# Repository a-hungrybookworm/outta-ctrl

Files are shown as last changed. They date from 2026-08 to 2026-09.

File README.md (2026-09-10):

# Outta-Ctrl

A custom 64-key linear mechanical keyboard designed from scratch - including a custom PCB, case, firmware, and even keycaps. 



## Features
* Custom PCB & layout
* 3D designed sandwich-mount case
* Custom RMK firmware
* Hotswappable MX-compatible switches
* Screw-in stabilisers
* Custom keycaps

## Components 
* Custom PCB
* 3D-printed case
* MX-compatible switches
* 1N4148 diodes
* Raspberry Pi Pico 
* Hotswap sockets
* Clear screw-in stabilizers
* Blank white (soon-to-be-doodled-on) keycaps

## Design Process
Initially, I planned the 64-key layout for my keyboard, and decided which components I would use. 

I then designed the PCB in KiCAD. I initially figured out which libraries/ footprints to use, connected them to form the keyboard matrix (row-to-col) and finally arranged the components and routed the traces.

Next, I learnt how to 3D model in Onshape, while simultaneously modelling the case. I used a sandwich mount for its simplicity, and split the case into two mutually screwable sections, as it was too big for the bed size. This will help in easy assembly and disassembly.

Finally, I wrote the RMK firmware, which I will flash to my Pi Pico to control the keyboard.

## Why I built it
I've been fascinated by understanding how most everyday objects work, and when I saw a HackClub programme offering to teach me how to build one of them, a keyboard, I was thrilled. Finally, I had the opportunity to learn how to design keyboard PCBs, model their cases, write their custom firmware, and deeply understand how these devices function.

## Challenges
While designing the keyboard, I found several tasks challenging, such as
* understanding the specifications and limitations of the different components
* accounting for all the specific holes and features of the components while designing the 3D models
* finding footprints/ 3D models for my components
* finding keycaps for my design size

## What I learnt
I started this ambitious project with no experience at all, and only a list of tutorials (credit to [Keeb](keeb.hackclub.com)). Now, I've learnt so much, including (sequentially) - 
* how Github repositories function 
* how to write in Markdown, and how to write a readme
* how to design a PCB in KiCAD
* the matrix layout/schematic required for keyboard PCBs
* how to use Onshape for 3D designing
* the different keyboard mounting styles, and parts of a case
* what keyboard firmware does, and how to write it
* about different keyboard components, and their functions

## Images 

__Schematic__:

Schematic

__Routed PCB__: 

 Routed

**3D Models:**

 __Top(Case)__:
 
Top

 __Plate__:

Plate

 __Base__:

Base

__Assembly__:

(without all keycaps/ stabs)

Assembly

## Bill of Materials

| SI No. | Name | Notes | Quantity | Price Per Unit | Total | Running Total | Price/Unit(USD) | Total (USD) | Running Total (USD) | Link |
| --- | --- | --- | --- | --- | --- | --- | --- | --- | --- | --- |
| 1 | Keygeek x MZ Y1 Keyboard Switch (Pack of 10) | MX-compatible Switches | 7 | 300 | 2100 | 2100 | 3.16 | 22.11 | 22.11 | [Switch](http://stackskb.com/store/keygeek-y1-keyboard-switch/) |
| 2 | PCB (manufactured by Robu) | Manufactured by Robu | 5 | 1062 | 5310 | 7410 | 11.18 | 55.89 | 78 | [PCB_Robu](https://github.com/a-hungrybookworm/outta-ctrl/blob/main/BOM/PCB%20Order.png) |
| 3 | Durock Clear Screw-In Stabilizers V2 | Screw-in stabilisers | 1 | 1650 | 1650 | 9060 | 17.37 | 17.37 | 95.37 | [Stabs](http://stackskb.com/store/durock-clear-screw-in-stabilizers-v2/) |
| 4 | Gateron Hotswap Sockets | Hotswap Sockets | 64 | 10 | 640 | 9700 | 0.11 | 6.74 | 102.11 | [Hotswap Switches](http://stackskb.com/store/gateron-hotswap-sockets/) |
| 5 | 1N4148 Diodes | Pack of 100, TH | 1 | 180 | 180 | 9880 | 1.89 | 1.89 | 104 | [Diodes](https://www.flipkart.com/elph-zener-diode-1n4148-pieces-100-electronic-components-hobby-kit/p/itmff7b2uhf4yng4) |
| 6 | Raspberry Pi Pico | MCU | 1 | 384 | 384 | 10264 | 4.04 | 4.04 | 108.04 | [Pico](https://robu.in/product/raspberry-pi-pico/) |
| 7 | Heat Set Threaded Round Female Insert Nut | M3, pack of 5 | 2 | 15 | 30 | 10294 | 0.16 | 0.32 | 108.36 | [Heat Set Insert](https://makerbazar.in/products/brass-heat-set-threaded-round-female-insert-nut?variant=48339035554032) |
| 8 | Philips Head Nuts & Bolts Set | M3, pack of 10 | 1 | 25 | 25 | 10319 | 0.26 | 0.26 | 108.62 | [Screws](https://makerbazar.in/products/philips-head-nuts-bolts-set-silver-plated-pack-of-10?variant=43604554383600) |
| 9 | Blank White Cherry Profile Keycaps | For later customization | 1 | 1000 | 1000 | 11319 | 10.53 | 10.53 | 119.15 | [Keycaps](https://stackskb.com/store/stackspbt-blank-white-cherry-profile-keycaps-113-key/) |
| 10 | 7u Spacebar | Custom key | 1 | 300 | 300 | 11619 | 3.16 | 3.16 | 122.31 | [Spacebar](https://curiositycaps.in/products/7u-spacebar-replacement-key) |

## Credits
This project was made possible through open-source hardware and design resources, and continuous support from the mechanical keyboard community. A special thank-you to the Hackclub YSWS Keeb, for inspiring me to take up this project, guiding me along the way, and most importantly, funding this project.

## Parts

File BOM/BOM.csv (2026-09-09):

SI No. | Name | Notes | Quantity | Price Per Unit | Total | Running Total | Price/Unit(USD) | Total (USD) | Running Total (USD) | Link
1 | Keygeek x MZ Y1 Keyboard Switch (Pack of 10) | MX-compatible Switches | 7 | 300 | 2100 | 2100 | 3.16 | 22.11 | 22.11 | http://stackskb.com/store/keygeek-y1-keyboard-switch/
2 | PCB (manufactured by Robu) | Manufactured by Robu | 5 | 1062 | 5310 | 7410 | 11.18 | 55.89 | 78 | https://github.com/a-hungrybookworm/outta-ctrl/blob/main/BOM/PCB Order.png
3 | Durock Clear Screw-In Stabilizers V2 | Screw-in stabilisers | 1 | 1650 | 1650 | 9060 | 17.37 | 17.37 | 95.37 | http://stackskb.com/store/durock-clear-screw-in-stabilizers-v2/
4 | Gateron Hotswap Sockets | Hotswap Sockets | 64 | 10 | 640 | 9700 | 0.11 | 6.74 | 102.11 | http://stackskb.com/store/gateron-hotswap-sockets/
5 | 1N4148 Diodes | Pack of 100, TH | 1 | 182 | 182 | 9882 | 1.92 | 1.92 | 104.02 | https://www.flipkart.com/elph-zener-diode-1n4148-pieces-100-electronic-components-hobby-kit/p/itmff7b2uhf4yng4
6 | Raspberry Pi Pico | MCU | 1 | 384 | 384 | 10266 | 4.04 | 4.04 | 108.06 | https://robu.in/product/raspberry-pi-pico/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
7 | Heat Set Threaded Round Female Insert Nut | M3, pack of 5 | 2 | 15 | 30 | 10296 | 0.16 | 0.32 | 108.38 | https://makerbazar.in/products/brass-heat-set-threaded-round-female-insert-nut?variant=48339035554032
8 | Philips Head Nuts & Bolts Set | M3, pack of 10 | 1 | 25 | 25 | 10321 | 0.26 | 0.26 | 108.64 | https://makerbazar.in/products/brass-heat-set-threaded-round-female-insert-nut?variant=48339035554032
9 | Blank White Cherry Profile Keycaps | For later customization | 1 | 1000 | 1000 | 11321 | 10.53 | 10.53 | 119.17 | https://stackskb.com/store/stackspbt-blank-white-cherry-profile-keycaps-113-key/
10 | 7u Spacebar | Custom key | 1 | 300 | 300 | 11621 | 3.16 | 3.16 | 122.33 | https://curiositycaps.in/products/7u-spacebar-replacement-key

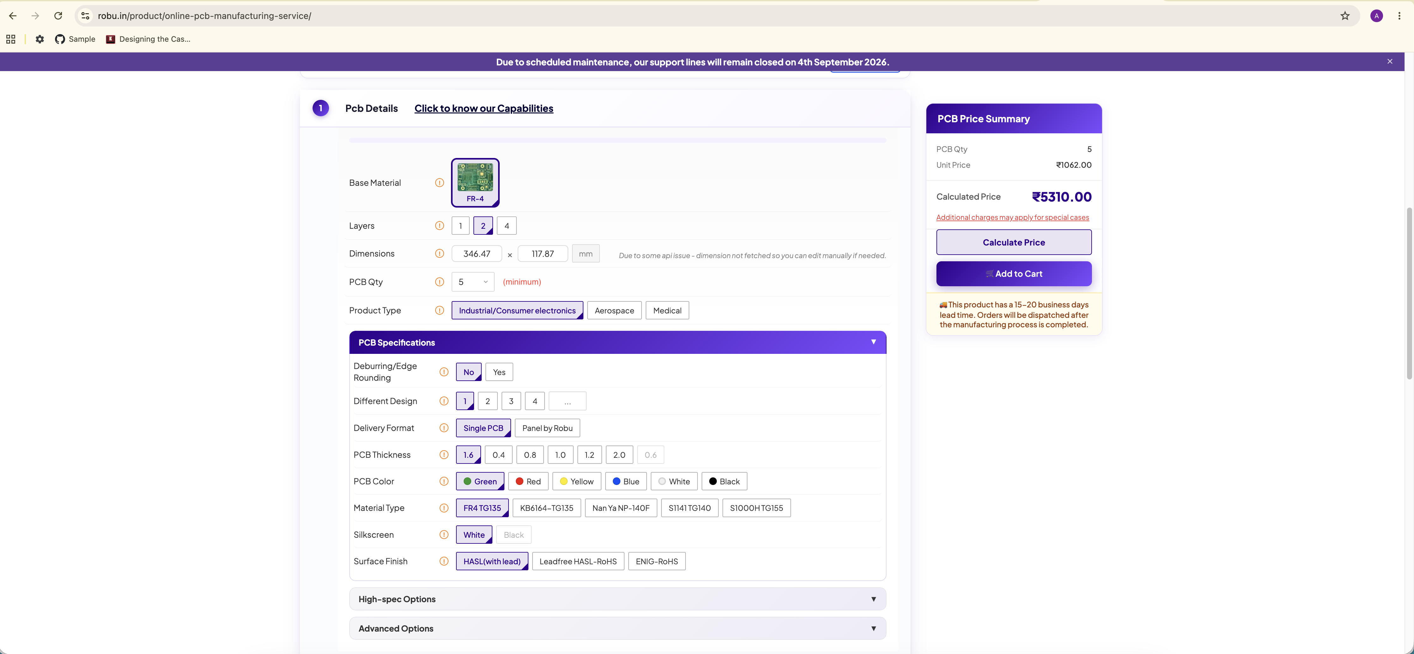
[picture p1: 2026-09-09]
BOM/PCB Order.png

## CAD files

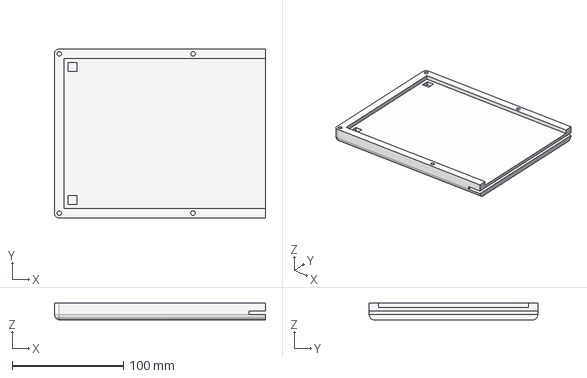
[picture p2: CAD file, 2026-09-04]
3D_Models/Keeb - Case_Right.step
189.3 x 151.3 x 15.2 mm

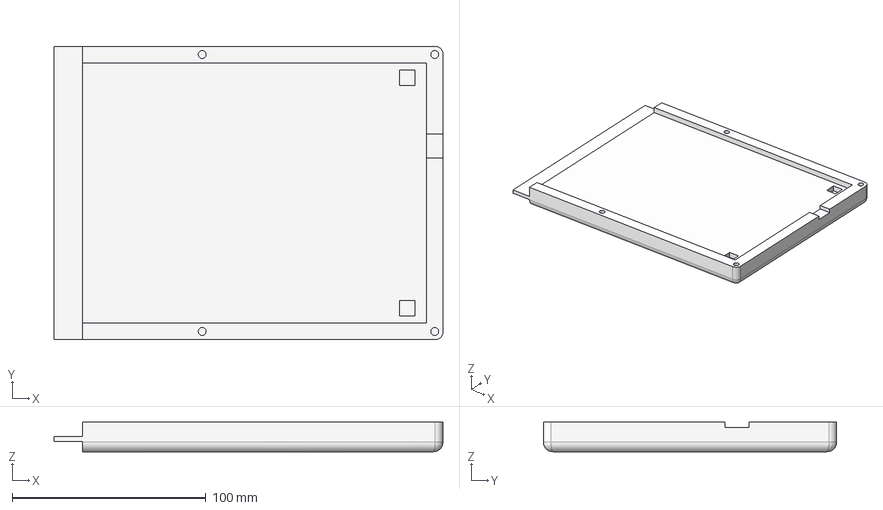
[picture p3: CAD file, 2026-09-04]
3D_Models/Keeb - Case_Left.step
200.7 x 151.3 x 15.2 mm

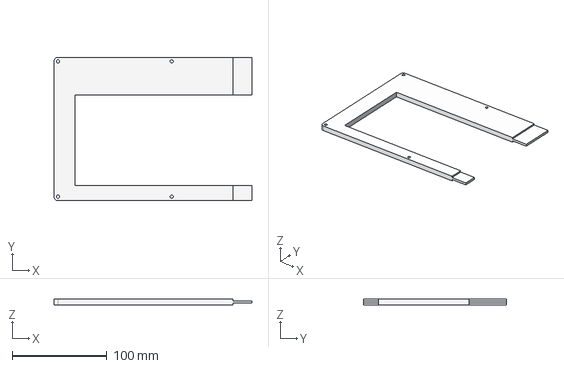
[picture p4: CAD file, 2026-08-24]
3D_Models/Keeb - Top_Left.step
209.1 x 151.3 x 6.00 mm

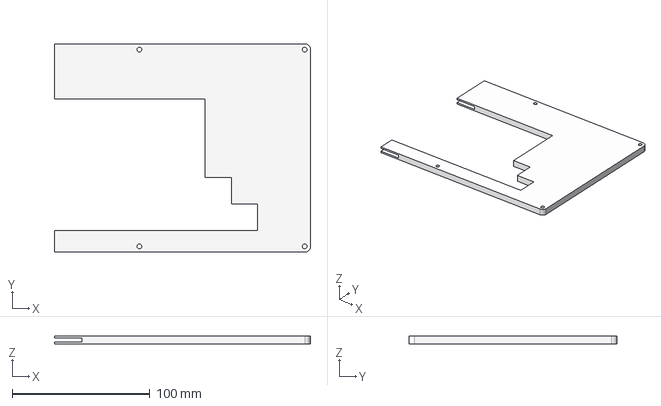
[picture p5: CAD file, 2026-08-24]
3D_Models/Keeb - Top_Right.step
185.9 x 151.3 x 6.00 mm

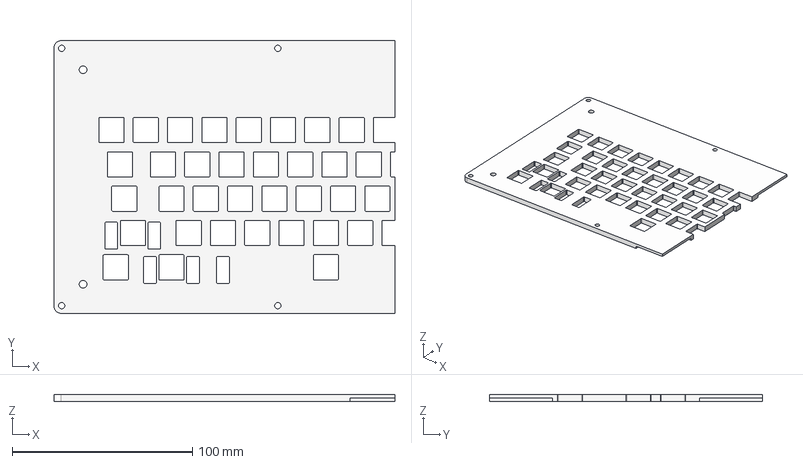
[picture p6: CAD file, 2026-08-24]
3D_Models/Keeb - Plate_Left.step
189.3 x 151.3 x 4.00 mm

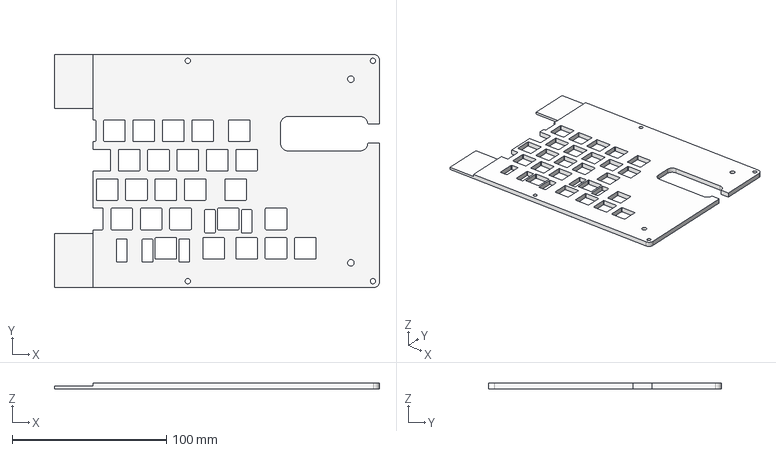
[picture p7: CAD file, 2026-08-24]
3D_Models/Keeb - Plate_Right.step
210.7 x 151.3 x 4.00 mm

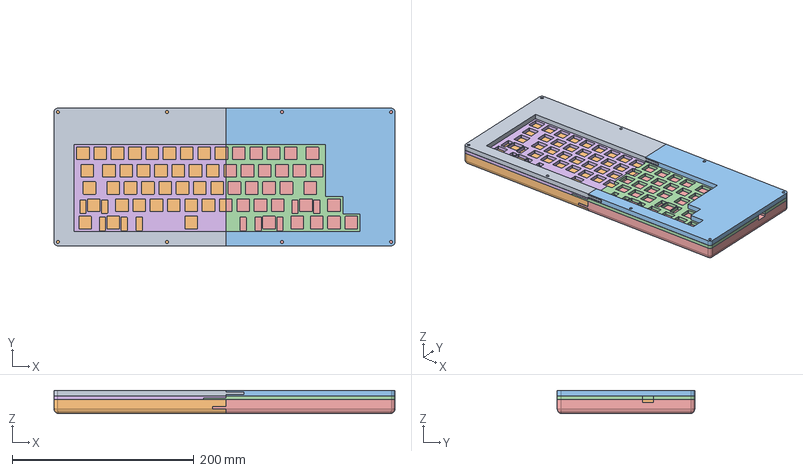
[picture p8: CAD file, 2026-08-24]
3D_Models/Keeb.step
375.2 x 151.3 x 25.4 mm
Top_Left
Case_Right
Top_Right
Plate_Right
Case_Left
Plate_Left

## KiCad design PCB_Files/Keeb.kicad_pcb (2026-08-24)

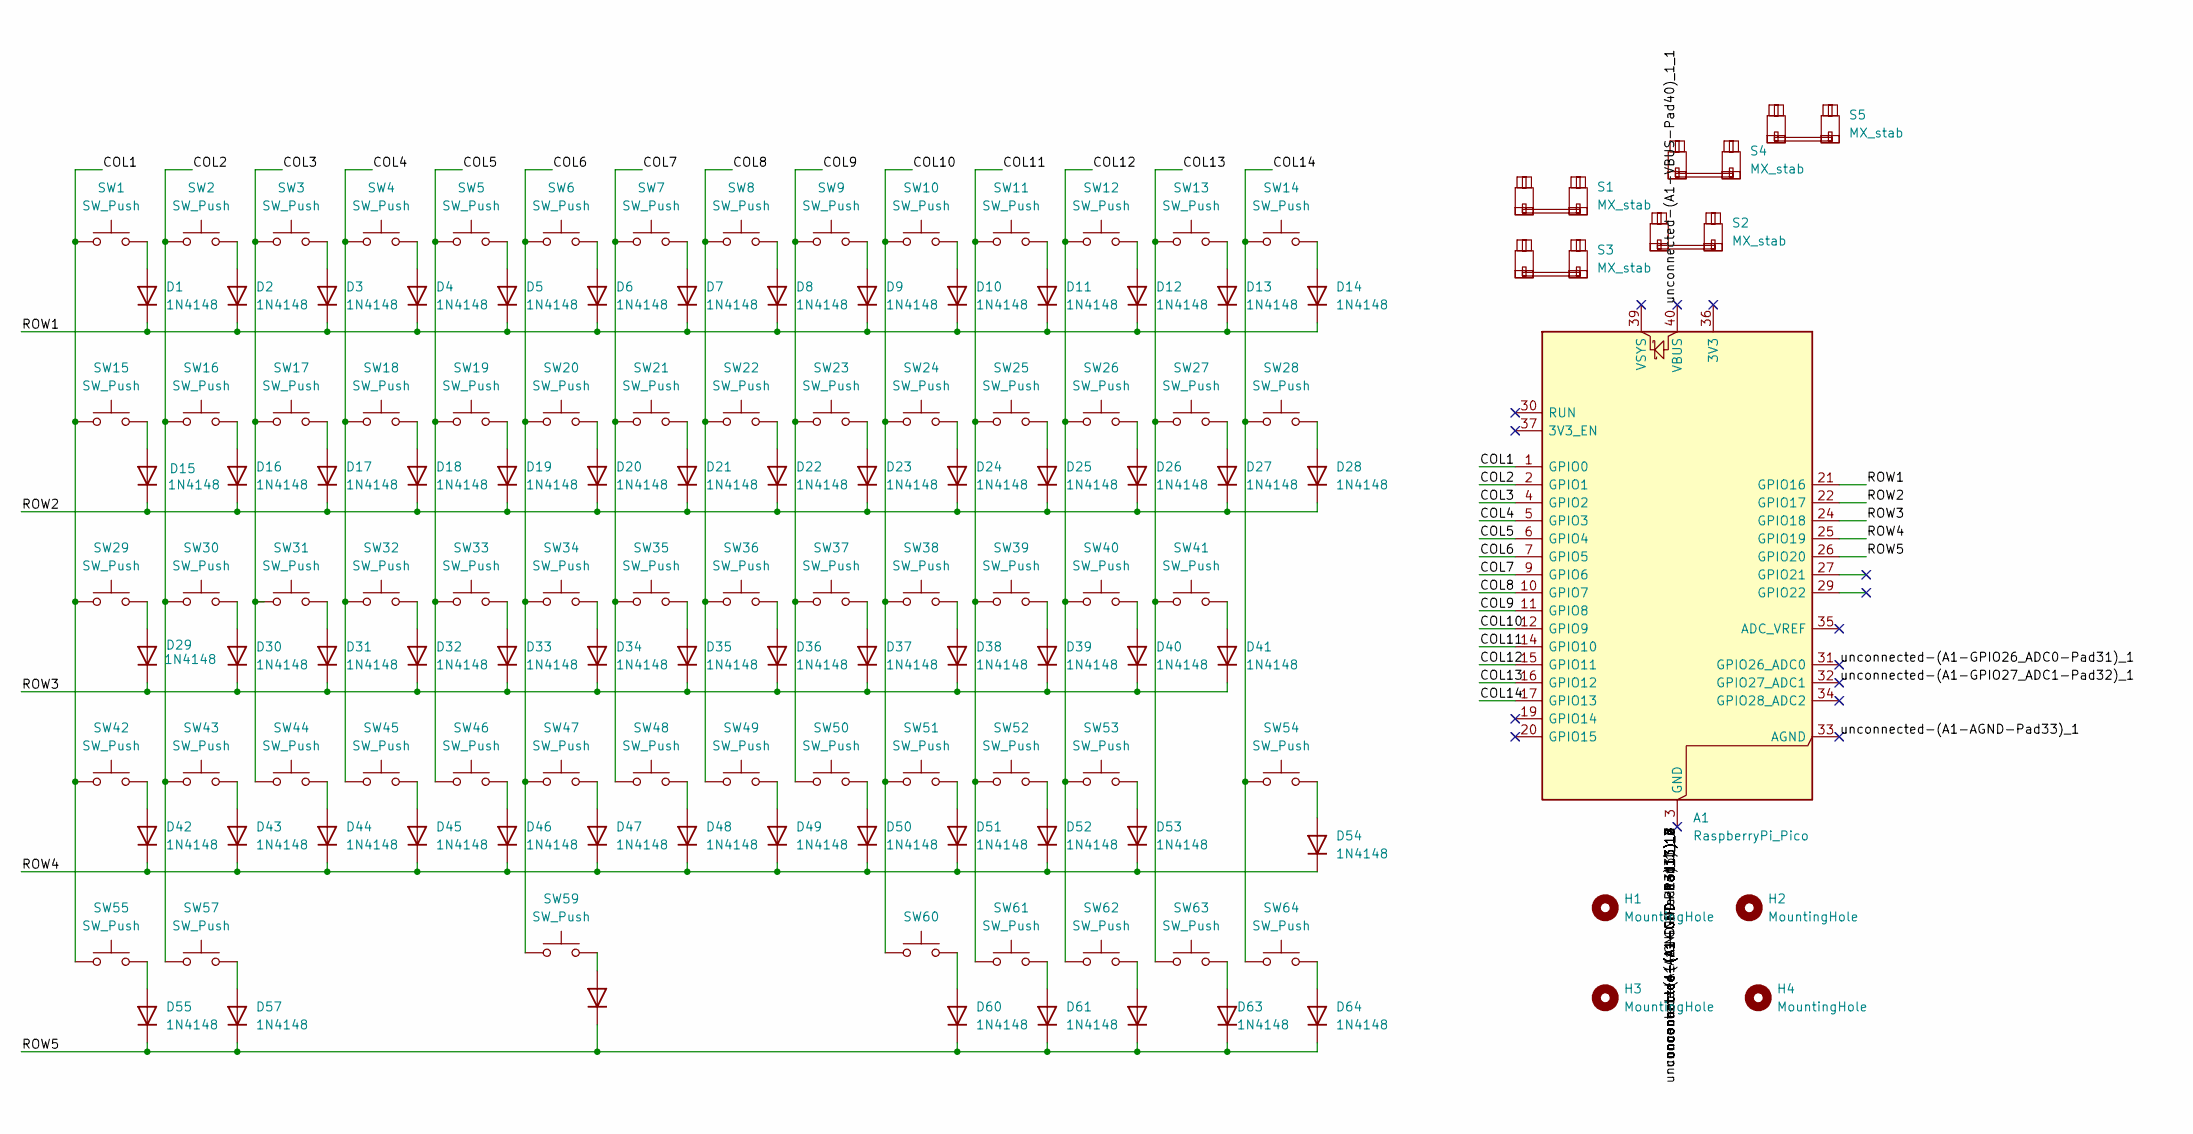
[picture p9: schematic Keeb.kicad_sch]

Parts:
A1: RaspberryPi_Pico; RaspberryPi_Pico_Common_Unspecified
D1, D2, D3, D4, D5, D6, D7, D8, D9, D10, D11, D12, D13, D14, D15, D16, D17, D18, D19, D20, D21, D22, D23, D24, D25, D26, D27, D28, D29, D30, D31, D32, D33, D34, D35, D36, D37, D38, D39, D40, D41, D42, D43, D44, D45, D46, D47, D48, D49, D50, D51, D52, D53, D54, D55, D57, D59, D60, D61, D62, D63, D64: 1N4148; D_DO-35_SOD27_P7.62mm_Horizontal
H1, H2, H3, H4: MountingHole; MountingHole_4.3mm_M4
S1, S3, S4, S5: MX_stab; STAB_MX_2u
S2: MX_stab; STAB_MX_7u
SW1, SW2, SW3, SW4, SW5, SW6, SW7, SW8, SW9, SW10, SW11, SW12, SW13, SW14, SW15, SW16, SW17, SW18, SW19, SW20, SW21, SW22, SW23, SW24, SW25, SW26, SW27, SW28, SW29, SW30, SW31, SW32, SW33, SW34, SW35, SW36, SW37, SW38, SW39, SW40, SW41, SW42, SW43, SW44, SW45, SW46, SW47, SW48, SW49, SW50, SW51, SW52, SW53, SW54, SW55, SW57, SW59, SW60, SW61, SW62, SW63, SW64: SW_Push; SW_MX_1u

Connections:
/COL1: A1.1 (GPIO0), SW1.1, SW15.1, SW29.1, SW42.1, SW55.1
/COL2: A1.2 (GPIO1), SW2.1, SW16.1, SW30.1, SW43.1, SW57.1
/COL3: A1.4 (GPIO2), SW3.1, SW17.1, SW31.1, SW44.1
/COL4: A1.5 (GPIO3), SW4.1, SW18.1, SW32.1, SW45.1
/COL5: A1.6 (GPIO4), SW5.1, SW19.1, SW33.1, SW46.1
/COL6: A1.7 (GPIO5), SW6.1, SW20.1, SW34.1, SW47.1, SW59.1
/COL7: A1.9 (GPIO6), SW7.1, SW21.1, SW35.1, SW48.1
/COL8: A1.10 (GPIO7), SW8.1, SW22.1, SW36.1, SW49.1
/COL9: A1.11 (GPIO8), SW9.1, SW23.1, SW37.1, SW50.1
/COL10: A1.12 (GPIO9), SW10.1, SW24.1, SW38.1, SW51.1, SW60.1
/COL11: A1.14 (GPIO10), SW11.1, SW25.1, SW39.1, SW52.1, SW61.1
/COL12: A1.15 (GPIO11), SW12.1, SW26.1, SW40.1, SW53.1, SW62.1
/COL13: A1.16 (GPIO12), SW13.1, SW27.1, SW41.1, SW63.1
/COL14: A1.17 (GPIO13), SW14.1, SW28.1, SW54.1, SW64.1
/ROW1: A1.21 (GPIO16), D1.1 (K), D2.1 (K), D3.1 (K), D4.1 (K), D5.1 (K), D6.1 (K), D7.1 (K), D8.1 (K), D9.1 (K), D10.1 (K), D11.1 (K), D12.1 (K), D13.1 (K), D14.1 (K)
/ROW2: A1.22 (GPIO17), D15.1 (K), D16.1 (K), D17.1 (K), D18.1 (K), D19.1 (K), D20.1 (K), D21.1 (K), D22.1 (K), D23.1 (K), D24.1 (K), D25.1 (K), D26.1 (K), D27.1 (K), D28.1 (K)
/ROW3: A1.24 (GPIO18), D29.1 (K), D30.1 (K), D31.1 (K), D32.1 (K), D33.1 (K), D34.1 (K), D35.1 (K), D36.1 (K), D37.1 (K), D38.1 (K), D39.1 (K), D40.1 (K), D41.1 (K)
/ROW4: A1.25 (GPIO19), D42.1 (K), D43.1 (K), D44.1 (K), D45.1 (K), D46.1 (K), D47.1 (K), D48.1 (K), D49.1 (K), D50.1 (K), D51.1 (K), D52.1 (K), D53.1 (K), D54.1 (K)
/ROW5: A1.26 (GPIO20), D55.1 (K), D57.1 (K), D59.1 (K), D60.1 (K), D61.1 (K), D62.1 (K), D63.1 (K), D64.1 (K)
/ROW6: A1.27 (GPIO21)
/unconnected-(A1-AGND-Pad33)_1: A1.33 (AGND)
/unconnected-(A1-AGND-Pad33)_1_1: A1.33 (AGND)
/unconnected-(A1-GND-Pad13)_12_2: A1.3 (GND)
/unconnected-(A1-GND-Pad13)_12_5: A1.23 (GND)
/unconnected-(A1-GND-Pad13)_12_8: A1.18 (GND)
/unconnected-(A1-GND-Pad13)_12_9: A1.28 (GND)
/unconnected-(A1-GND-Pad13)_12_10: A1.13 (GND)
/unconnected-(A1-GND-Pad13)_12_11: A1.8 (GND)
/unconnected-(A1-GND-Pad13)_12_13: A1.38 (GND)
/unconnected-(A1-GPIO26_ADC0-Pad31)_1: A1.31 (GPIO26_ADC0)
/unconnected-(A1-GPIO26_ADC0-Pad31)_1_1: A1.31 (GPIO26_ADC0)
/unconnected-(A1-GPIO27_ADC1-Pad32)_1: A1.32 (GPIO27_ADC1)
/unconnected-(A1-GPIO27_ADC1-Pad32)_1_1: A1.32 (GPIO27_ADC1)
/unconnected-(A1-VBUS-Pad40)_1_1: A1.40 (VBUS)
/unconnected-(A1-VBUS-Pad40)_1_1_1: A1.40 (VBUS)
unnamed: D1.2 (A), SW1.2
unnamed: D2.2 (A), SW2.2
unnamed: D3.2 (A), SW3.2
unnamed: D4.2 (A), SW4.2
unnamed: D5.2 (A), SW5.2
unnamed: D6.2 (A), SW6.2
unnamed: D7.2 (A), SW7.2
unnamed: D8.2 (A), SW8.2
unnamed: D9.2 (A), SW9.2
unnamed: D10.2 (A), SW10.2
unnamed: D11.2 (A), SW11.2
unnamed: D12.2 (A), SW12.2
unnamed: D13.2 (A), SW13.2
unnamed: D14.2 (A), SW14.2
unnamed: D15.2 (A), SW15.2
unnamed: D16.2 (A), SW16.2
unnamed: D17.2 (A), SW17.2
unnamed: D18.2 (A), SW18.2
unnamed: D19.2 (A), SW19.2
unnamed: D20.2 (A), SW20.2
unnamed: D21.2 (A), SW21.2
unnamed: D22.2 (A), SW22.2
unnamed: D23.2 (A), SW23.2
unnamed: D24.2 (A), SW24.2
unnamed: D25.2 (A), SW25.2
unnamed: D26.2 (A), SW26.2
unnamed: D27.2 (A), SW27.2
unnamed: D28.2 (A), SW28.2
unnamed: D29.2 (A), SW29.2
unnamed: D30.2 (A), SW30.2
unnamed: D31.2 (A), SW31.2
unnamed: D32.2 (A), SW32.2
unnamed: D33.2 (A), SW33.2
unnamed: D34.2 (A), SW34.2
unnamed: D35.2 (A), SW35.2
unnamed: D36.2 (A), SW36.2
unnamed: D37.2 (A), SW37.2
unnamed: D38.2 (A), SW38.2
unnamed: D39.2 (A), SW39.2
unnamed: D40.2 (A), SW40.2
unnamed: D41.2 (A), SW41.2
unnamed: D42.2 (A), SW42.2
unnamed: D43.2 (A), SW43.2
unnamed: D44.2 (A), SW44.2
unnamed: D45.2 (A), SW45.2
unnamed: D46.2 (A), SW46.2
unnamed: D47.2 (A), SW47.2
unnamed: D48.2 (A), SW48.2
unnamed: D49.2 (A), SW49.2
unnamed: D50.2 (A), SW50.2
unnamed: D51.2 (A), SW51.2
unnamed: D52.2 (A), SW52.2
unnamed: D53.2 (A), SW53.2
unnamed: D54.2 (A), SW54.2
unnamed: D55.2 (A), SW55.2
unnamed: D57.2 (A), SW57.2
unnamed: D59.2 (A), SW59.2
unnamed: D60.2 (A), SW60.2
unnamed: D61.2 (A), SW61.2
unnamed: D62.2 (A), SW62.2
unnamed: D63.2 (A), SW63.2
unnamed: D64.2 (A), SW64.2

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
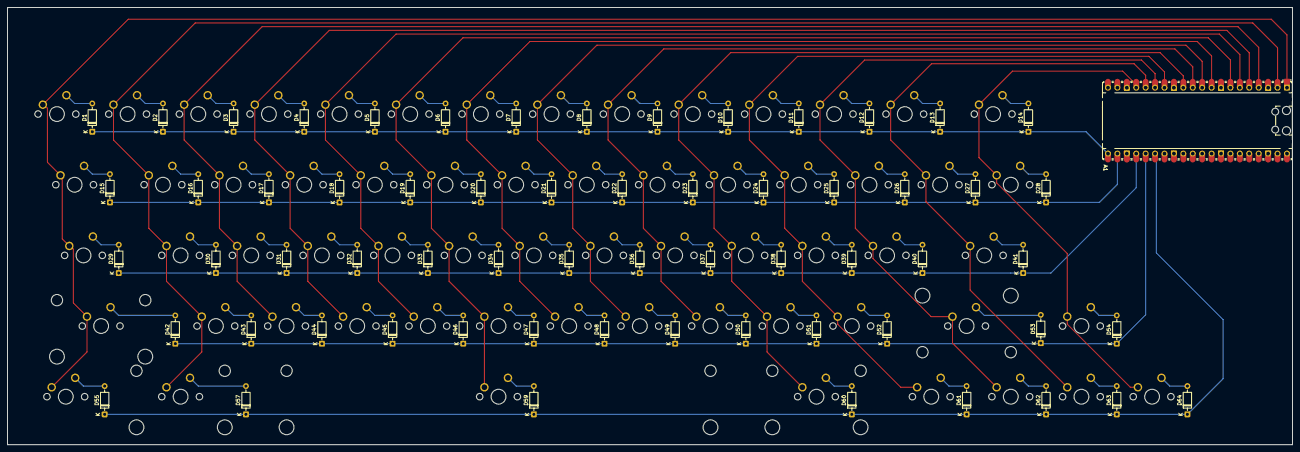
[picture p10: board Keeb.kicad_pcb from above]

Board: 2 copper layers, 346.5 x 117.9 mm, 130 parts (0 on the bottom side), 81 nets.

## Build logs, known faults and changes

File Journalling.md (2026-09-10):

# Writing the BOM & Readme

## Total time spent: 5.5 hours

## 5.30 p.m.

I don't know if this time counts!

I'm using linear Keygeek x MZ Y1 switches, fixed in hotswap sockets for ease of use, with screw-in stabilisers (transparent). My keycaps are blank white - so I can doodle on them, and create my custom design, and also so I can easily replace them, or find alternative keycaps, as my keyboard layout is a little bit different from standard ones. I also didn't know whether to add the PCB (indivudal or total) and 3D model costs to the BOM.

## 7.00 p.m.

Done with the BOM - I didn't include 3D model costs as that would make it too expensive... now doing the readme.

## 11.00 p.m.

Done with the readme... submitting!

~a-hungrybookworm

09/09/2026

# Writing Firmware

## Total time spent: 2 hours

I've used RMK firmware, and I wrote it using GitHub actions (I don't know how to code in Rust!). It was pretty easy, as I kept the extra functions to a minimum. I had to first map the keyboard matrix in a toml file - the row and column pins, switch positions, and the keymap I'm going to assign to them. I wrote a keymap for vial too, so I can configure the keyboard easily when I'm flashing the firmware. I then downloaded the .uf2 generated by the Actions, and I've added it to this repo - the file I'm going to flash to the Pico.

~a-hungrybookworm

04/09/2026

# Finishing the 3D Design

## Total time spent : 10 hours

I *did* spend a lot of time on this, but it's my first time using Onshape, or 3D designing anything much.

I'm using a sandwich mount, with a top part, plate and case all screwed together, and the plate screwed to the PCB. It might turn out a little stiff, but I don't really mind, as this mounting style was easy to design and will use less screws altogether >_<. 

I'm using 8 M3s with heat set inserts, and 4 M4s for the plate to PCB. The plate to PCB screws aren't necessary, but I'm scared that the PCB will rattle in the case, or that the switches will wobble, so I put the holes in there just in case.

For the top of the plate, I downloaded a dxf drawing from Keyboard Layout Editor NG, where I designed my keyboard. It included the holes for stabilisers too, and that was really helpful. 

I also had to split the case, as it was more than 300mm wide, so I designed a tongue-and-groove joint between the parts. For the plate, which was too thin, I put a sliding-groove-thingy - I'm not really sure if it has a specific name.

3D model

^ I couldn't find models for the longer keycaps, or the stabilisers, but their measurements are included in the design, so hopefully it's okay.

Firmware!

~a-hungrybookworm

24/08/2026

# 3D Model

## Total time spent: 2.5 hours

## 12.00 p.m.

I figured out my PCB doesn't have 3D models for the switches and stabilisers! I'm seraching them up now on GrabCAD...

## 1.30 p.m.

I'm finally done with adding the switches. The marbastlib footprint disappeared, so I couldn't update it, and I had to manually add the Cherry MX 3D model I found to each switch. ;(

Switches

After a lot of rotating the switch and moving it in each axis, the PCB looks like this... Adding the keycaps and stabs now.

## 2.30 p.m.

I couldn't rly find long keycaps, so I've put the short ones for now.

Keycaps

Anyway I'll start the 3D design.

~ a-hungrybookworm

15/08/2026

# Routing

## Total time spent: 1.5 hours

## 11.00 a.m.

Beginning the routing!

## 12.30 p.m.

I'm finally done! I've routed the columns on the front copper layer, and the diode connections & rows on the bottom copper layer. There was a bit of trouble with the DRC, but I finally got the 53 initial errors down to 1 warning, by adjusting the settings for an 'Exposed Copper Keep Out' area, and just moving the components around. I haven't added any ground pours, as it seems a bit unnecessary, and I don't even have a GND net. I've added mounting holes though, and my Pico USB port will hang off the PCB.

 Routed

I generated the gerbers and drill files, and now I've added them to the repo.

All set for the 3D design!

~a-hungrybookworm

24/07/2026

# Final Touches 

## Total time spent: 1 hours

## 5.30 p.m.

I designed the keycap covers and *another* keyboard layout, with less switches on the bottom row cause I don't even think they're needed.

keyboard-layout6

## 6.00 p.m.
Updated schematic and pcb layout.

Schematic_idk

PCB

~ a-hungrybookworm

23/07/2026

# Back to the Schematic

## Total time spent: 2 hours

## 7.00 p.m

Hopefully this is the last PCB entry :)

The schematic is now fully edited for easy routing! I had to juggle the switches and diodes along the rows and columns, but it now looks like this - 

Schematic_last

I've made the PCB using a custom grid of (2.38u x 2.38u), that is, 1/8 of a unit in millimetre (19.05mm). After a lot of dragging stuff and aligning it, it looks like this - 

 PCB

 \# Ready for routing!

~a-hungrybookworm

20/07/2026

# PCB Design

## Total time spent: 1 hour

## 7.00 p.m. 

I've been editing the sizes of the keys, and this is what I've ended up with! All the keys are indented now, so I don't have to type on keys arranged in weird straight columns. Each row is 14.5u long, and each column is 5u long. Finally, it all fits on the Pi Pico.

Schematic_Drawing

I edited the rows and columns too, so I can add the arrow keys (and the right shift), and I've removed the superfluous stabilisers - so now I have only 3!

Schematic_3

The Slack chat absolutely rocks - now I'm using 2.38125mm x 4.7625mm grids (basically 19.05 divided by 8 and 4 respectively) and that's soo much better :). 

~ a-hungrybookworm

04/07/2026

# KiCad

## Total time spent: 2 hours

## 3.00 p.m.

I've just installed KiCad, and installed the MarbastLib library. The Slack chat really helped with the schematic!

Schematic

I'm placing the swithces in the matrix now.

## 5.00 p.m

I'm pretty much done with my schematic now. It doesn't have arrow keys - to save space, but other than that it seems pretty fine.

Schematic_2

I'll do the routing tomorrow.

~ a-hungrybookworm

28/06/2026

# Setting Up
This is my first Hackclub project!

I've set up Hackatime, and I've been going through the (really long) Slack chats in #keeb. This is also like my first time using Github - and I'm still learning about repos, commits, pull requests and all the other stuff. 

I'm really excited to build this keyboard, and I hope my inexperienced design \**works**\. (I'm learning Markdown too!)

~ a-hungrybookworm

26/ 06/ 2026

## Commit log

2026-08-24 Adding the 3D Models
    I've split each layer (out of the case, plate, and top part), and added each part (right and left) separately. 'Keeb.stl' shows the full model, and for the Onshape document, go here -
    https://cad.onshape.com/documents/6f7a7e00666188f7ad4cf98b/w/f1435142402e02a68e5f24dd/e/d5e9a1b6849998dde5a38184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
    [Keeb - Case_Left.stl, Keeb - Case_Right.stl, Keeb - Plate_Left.stl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]
2026-08-24 PCB Files
    Gerbers and drill files
    [Keeb-B_Cu.gbr, Keeb-B_Mask.gbr, Keeb-B_Paste.gbr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]
2026-08-24 Delete the directory to rename it
    (PCB_Design)
    [Keeb-B_Cu.gbr, Keeb-B_Mask.gbr, Keeb-B_Paste.gbr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]
2026-08-24 The holes for the keyboard plate
    Downloaded from Keyboard Layout Editor
    [keyboard-plate.dxf]
2026-08-24 Adding files for the PCB and CAD
    The PCB folder includes the drill files and gerbers.
    The CAD folder has the three parts of the case (the bottom, plate, and top) split into their right and left halves. The 'Keeb.stl' file includes the whole model.
    [Keeb - Case_Left.stl, Keeb - Case_Right.stl, Keeb - Plate_Left.stl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]
2026-08-24 Schematic and Layout Uploads
    [Keeb.kicad_pcb, Keeb.kicad_sch]
2026-08-24 Adding CAD files
    I've split the 3 parts of the case (top, plate, and bottom/case) into the right and left parts and uploaded them. The 'Keeb.step' file contains the whole model.
    [Keeb - Case_Left.step, Keeb - Case_Right.step, Keeb - Plate_Left.step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]
2026-09-04 Upload schematic and pcb design files
    [Keeb.kicad_pcb, Keeb.kicad_sch]
2026-09-04 Modify case
    [Keeb - Case_Left.step, Keeb - Case_Right.step]
2026-09-09 Adding file for BOM
2026-09-09 Added excel sheet and csv
    [BOM.csv, BOM.xlsx]
2026-09-09 BOM uploads
    [BOM.csv, BOM.xlsx]
2026-09-09 correct BOM.md
2026-09-09 Upload Excel sheet
    [BOM.xlsx]
2026-09-09 Upload xlsx and csv
    [BOM.csv, BOM.xlsx]
2026-11-06 Add gerbers
2026-11-06 Delete Gerbers.zip
    organise into folders
2026-11-06 Add .kicad_pro file
2026-11-13 Add BOM
2026-11-13 Add BOM directory
2026-11-13 Edit BOM
2026-11-13 Add BOM.csv
2026-11-13 Edit BOM numbering
2026-11-13 Fix BOM.csv
2026-11-13 Fix BOM numbering
    Replaced removed items in BOM with new entries, maintaining the same structure and data.
2026-11-13 Edit BOM notes
2026-11-13 BOM edits
